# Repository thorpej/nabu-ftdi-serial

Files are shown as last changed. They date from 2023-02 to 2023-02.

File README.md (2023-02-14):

# nabu-ftdi-serial
A serial interposer board for NABU PCs with a FTDI USB-serial adapter and
hardware flow control

This is a simple serial interposer board for NABU PCs that intercepts
the Tx and Rx signals from the TR1863 UART and routes them to an FTDI
USB-serial adapter rather than to the RS422 line drivers on the NABU
main board.

In addition to intercepting the Tx and Rx signals, it also provides two
enhancements:

* The option to use a 1.8432MHz oscillator to generate a 115.2K baud
  rate on the UART, rather than the stock 111.8K baud that the NABU's
  clock generates.  Two different oscillator footprints are provided,
  for your convenience.  A jumper is provided to select the clock source.

* The option to enable hardware flow control.  This is done by connecting
  the TR1863's _DR_ signal (Data Received) to the _CTS_ input on the FTDI.
  Because _DR_ is active-high and _CTS_ is active-low, a pending receive
  interrupt effectively de-asserts _CTS_, which will cause the sender to
  pause transmitting until the interrupt has been serviced.

To build this board you're oging to need an FTDI USB -> serial interface
chip mounted on some sort of break-out board.  The board provides 2
footprints to provide some flexibility.

The first footprint is for a 6-pin right-angle pin header that is meant
for an Adafruit 6-pin female FTDI connector.  Such a connector can be
found on the [Adafruit FTDI Friend](https://www.adafruit.com/product/284),
the [Adafruit FTDI Serial TTL-232 Cable](https://www.adafruit.com/product/70),
or the [Adafruit FTDI Serial TTL-232 USB Type C 5V Cable](https://www.adafruit.com/product/4364).
There are other cables out there with a compatible 6-pin connector,
but I specifically referenced the pin configuration of the Adafruit
products.

The other option is one of the FTDI FT232RL boards that are all over
Ali Express.  I ordered [this one](https://www.aliexpress.us/item/2251832463833524.html),
but there are lots of identical boards floating around.

This board is 99.9% the work of Kris Sekula (MyGeekyHobby.com).  All I did
was add the hardware flow control modification.  Kudos to Kris for publishing
his idea [here](https://github.com/Kris-Sekula/NABU/tree/main/RS422Alternative).

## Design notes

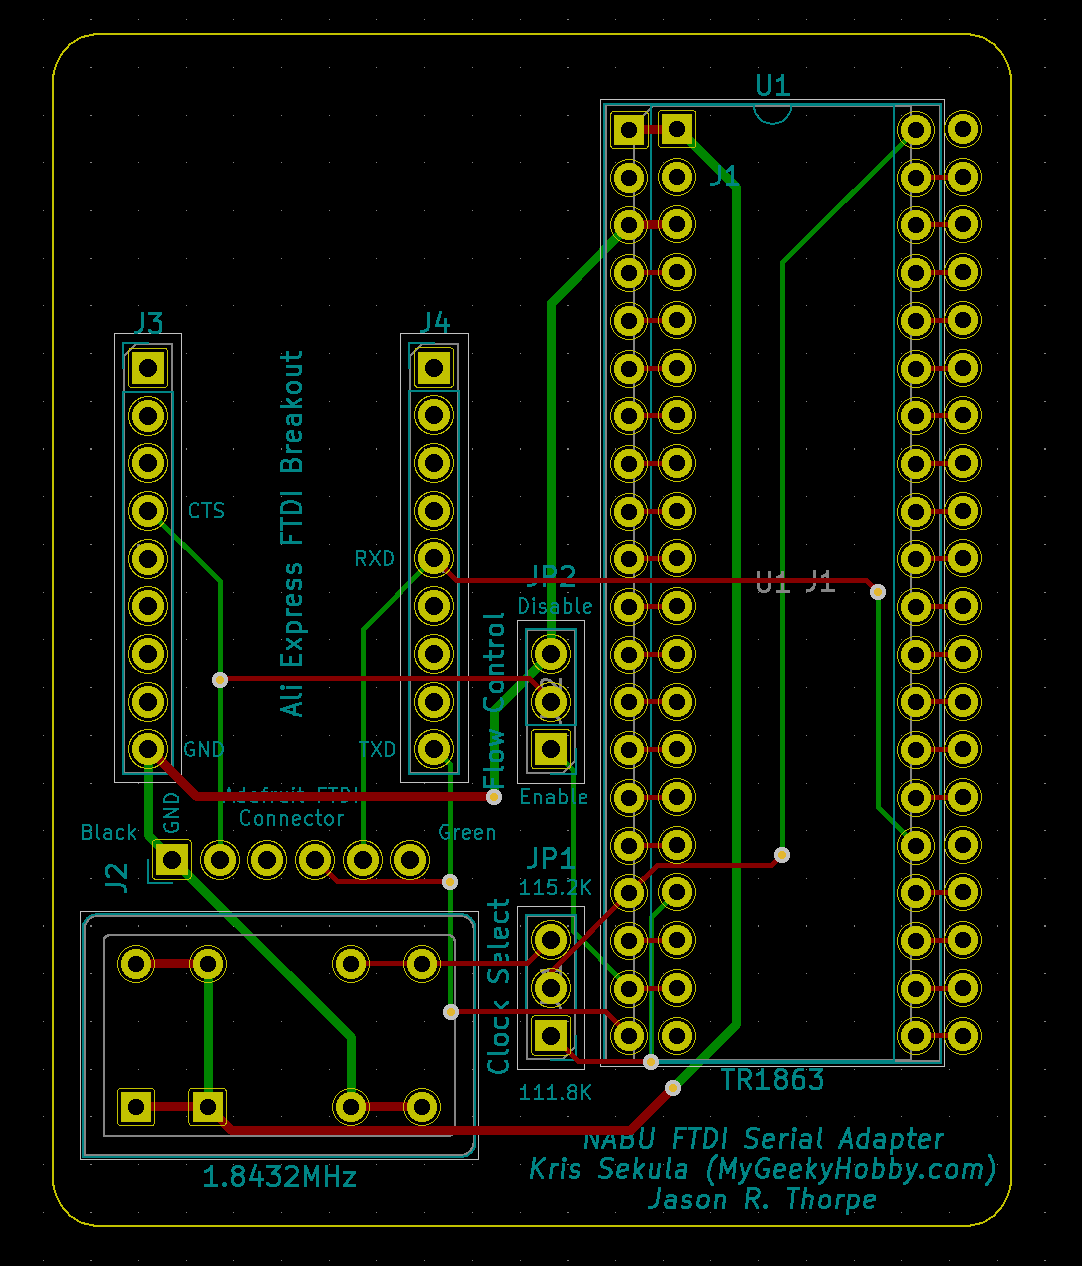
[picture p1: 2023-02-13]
nabu-ftdi-serial-pcb.png

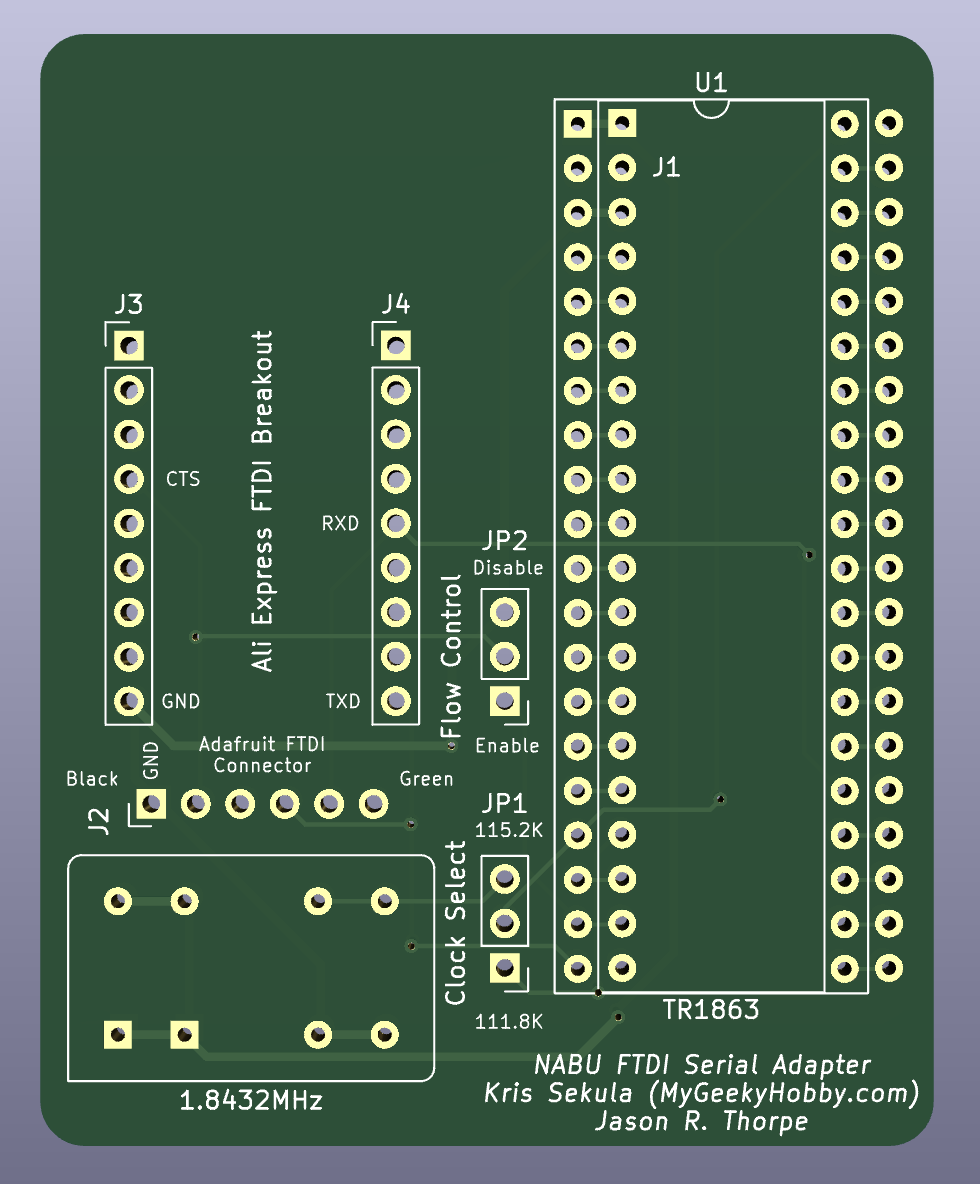
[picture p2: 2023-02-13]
nabu-ftdi-serial-pcb-render.png

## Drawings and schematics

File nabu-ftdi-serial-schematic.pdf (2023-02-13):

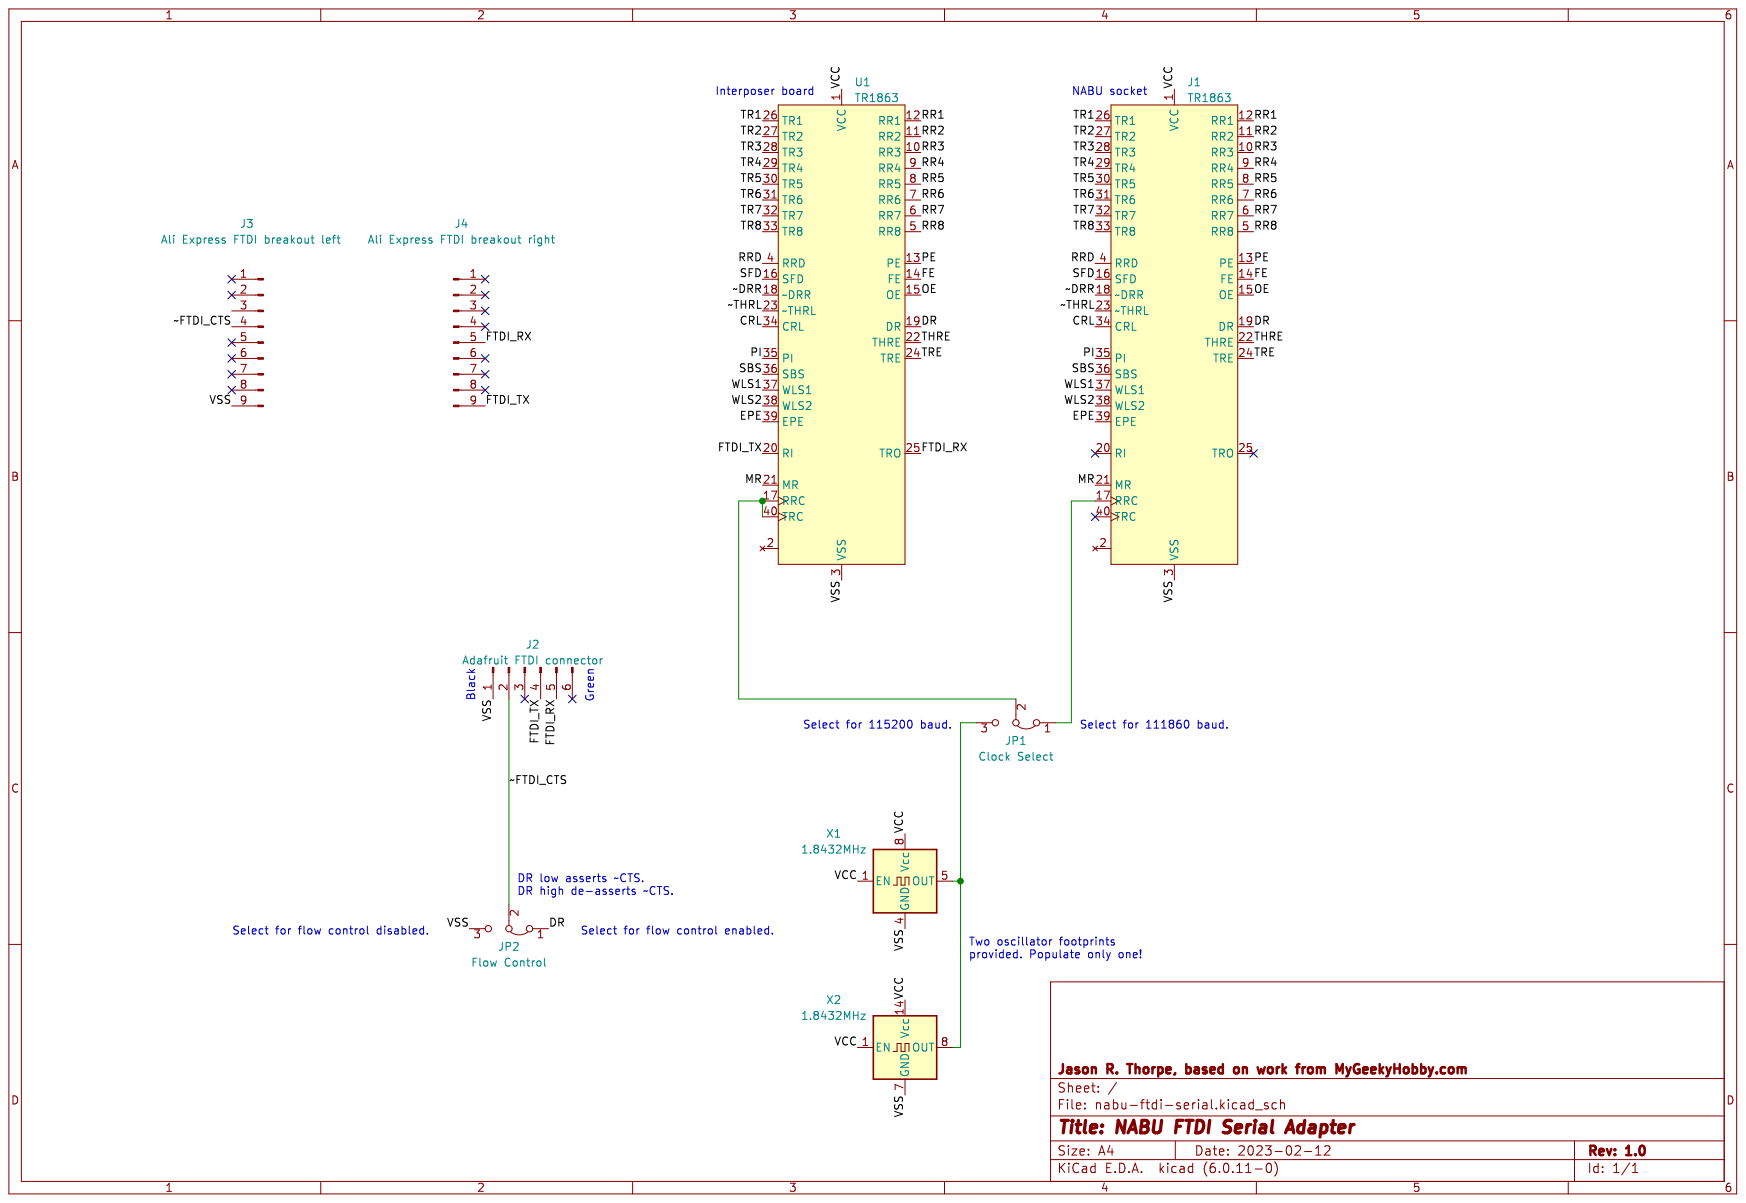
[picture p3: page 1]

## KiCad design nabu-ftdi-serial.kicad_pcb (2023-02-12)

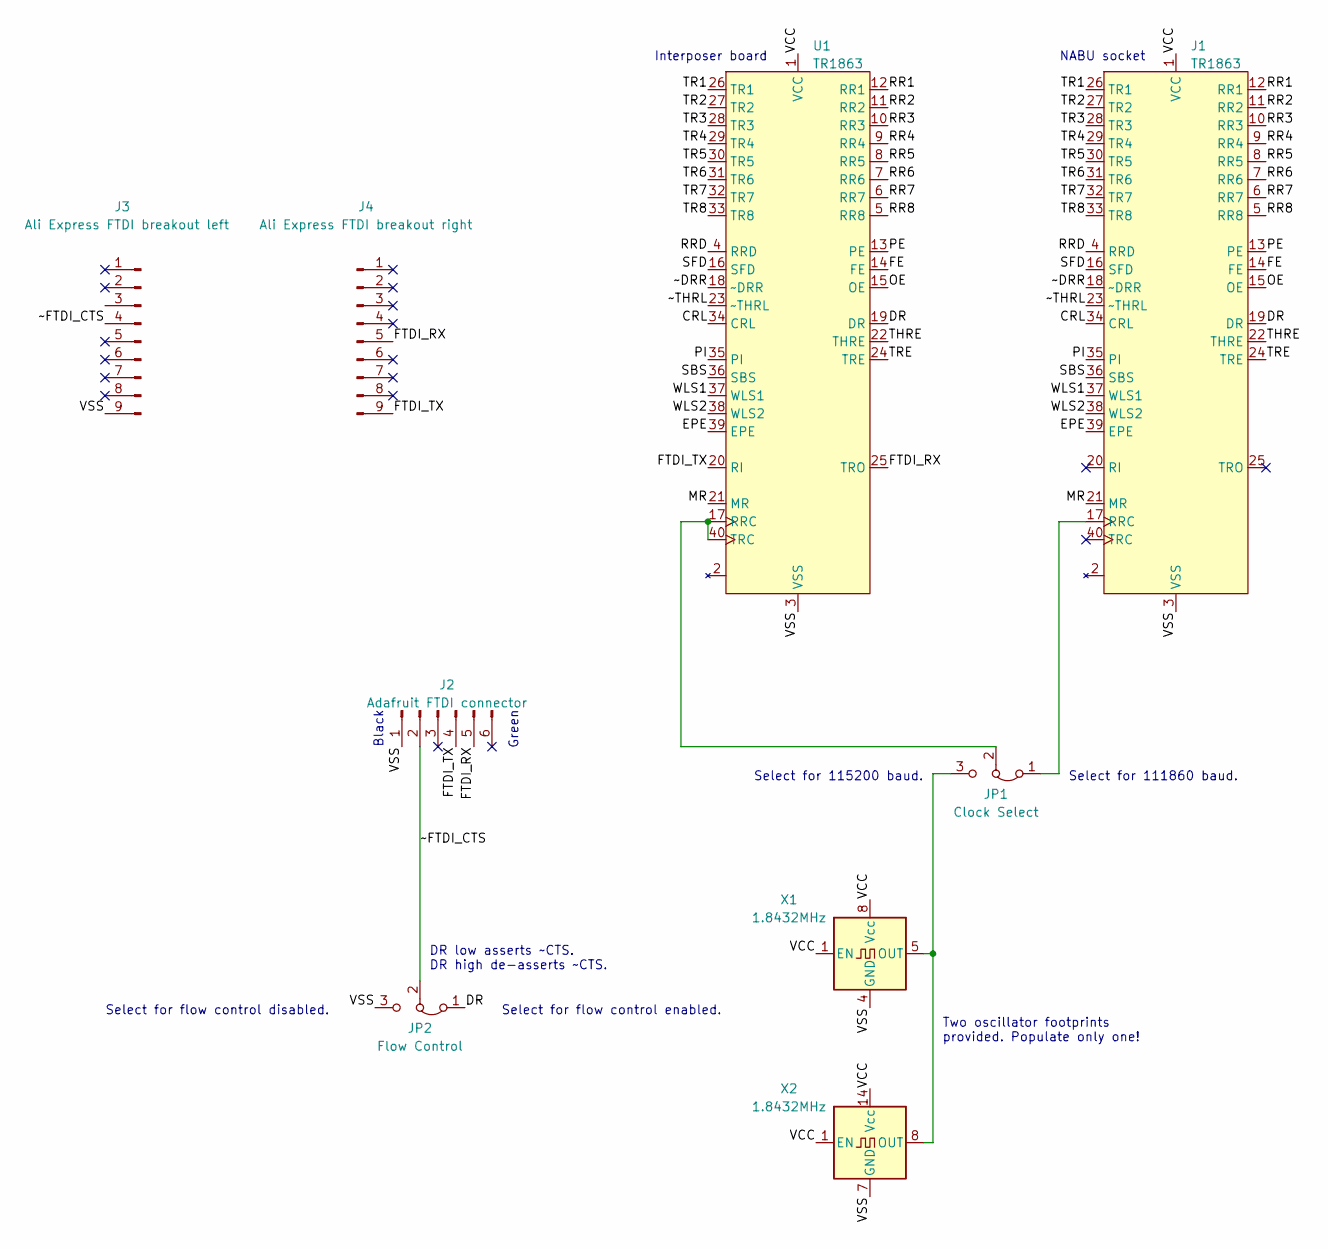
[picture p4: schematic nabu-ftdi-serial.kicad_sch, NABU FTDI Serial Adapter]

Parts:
J1: TR1863; DIP-40_W15.24mm
J2: Adafruit FTDI connector; PinHeader_1x06_P2.54mm_Horizontal
J3: Ali Express FTDI breakout left; PinHeader_1x09_P2.54mm_Vertical
J4: Ali Express FTDI breakout right; PinHeader_1x09_P2.54mm_Vertical
JP1: Clock Select; PinHeader_1x03_P2.54mm_Vertical
JP2: Flow Control; PinHeader_1x03_P2.54mm_Vertical
U1: TR1863; DIP-40_W15.24mm_Socket
X1: 1.8432MHz; Oscillator_DIP-8
X2: 1.8432MHz; Oscillator_DIP-14

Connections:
/CRL: J1.34 (CRL), U1.34 (CRL)
/DR: J1.19 (DR), JP2.1 (A), U1.19 (DR)
/EPE: J1.39 (EPE), U1.39 (EPE)
/FE: J1.14 (FE), U1.14 (FE)
/FTDI_RX: J2.5, J4.5, U1.25 (TRO)
/FTDI_TX: J2.4, J4.9, U1.20 (RI)
/MR: J1.21 (MR), U1.21 (MR)
/OE: J1.15 (OE), U1.15 (OE)
/PE: J1.13 (PE), U1.13 (PE)
/PI: J1.35 (PI), U1.35 (PI)
/RR1: J1.12 (RR1), U1.12 (RR1)
/RR2: J1.11 (RR2), U1.11 (RR2)
/RR3: J1.10 (RR3), U1.10 (RR3)
/RR4: J1.9 (RR4), U1.9 (RR4)
/RR5: J1.8 (RR5), U1.8 (RR5)
/RR6: J1.7 (RR6), U1.7 (RR6)
/RR7: J1.6 (RR7), U1.6 (RR7)
/RR8: J1.5 (RR8), U1.5 (RR8)
/RRD: J1.4 (RRD), U1.4 (RRD)
/SBS: J1.36 (SBS), U1.36 (SBS)
/SFD: J1.16 (SFD), U1.16 (SFD)
/THRE: J1.22 (THRE), U1.22 (THRE)
/TR1: J1.26 (TR1), U1.26 (TR1)
/TR2: J1.27 (TR2), U1.27 (TR2)
/TR3: J1.28 (TR3), U1.28 (TR3)
/TR4: J1.29 (TR4), U1.29 (TR4)
/TR5: J1.30 (TR5), U1.30 (TR5)
/TR6: J1.31 (TR6), U1.31 (TR6)
/TR7: J1.32 (TR7), U1.32 (TR7)
/TR8: J1.33 (TR8), U1.33 (TR8)
/TRE: J1.24 (TRE), U1.24 (TRE)
/VCC: J1.1 (VCC), U1.1 (VCC), X1.1 (EN), X1.8 (Vcc), X2.1 (EN), X2.14 (Vcc)
/VSS: J1.3 (VSS), J2.1, J3.9, JP2.3 (B), U1.3 (VSS), X1.4 (GND), X2.7 (GND)
/WLS1: J1.37 (WLS1), U1.37 (WLS1)
/WLS2: J1.38 (WLS2), U1.38 (WLS2)
/~DRR: J1.18 (~DRR), U1.18 (~DRR)
/~FTDI_CTS: J2.2, J3.4, JP2.2 (C)
/~THRL: J1.23 (~THRL), U1.23 (~THRL)
unnamed: J1.17 (RRC), JP1.1 (A)
unnamed: JP1.3 (B), X1.5 (OUT), X2.8 (OUT)
unnamed: JP1.2 (C), U1.17 (RRC), U1.40 (TRC)

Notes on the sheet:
Green
Select for flow control disabled.
Select for flow control enabled.
NABU socket
Interposer board
Two oscillator footprints provided. Populate only one!
Select for 111860 baud.
Black
DR low asserts ~CTS. DR high de-asserts ~CTS.
Select for 115200 baud.

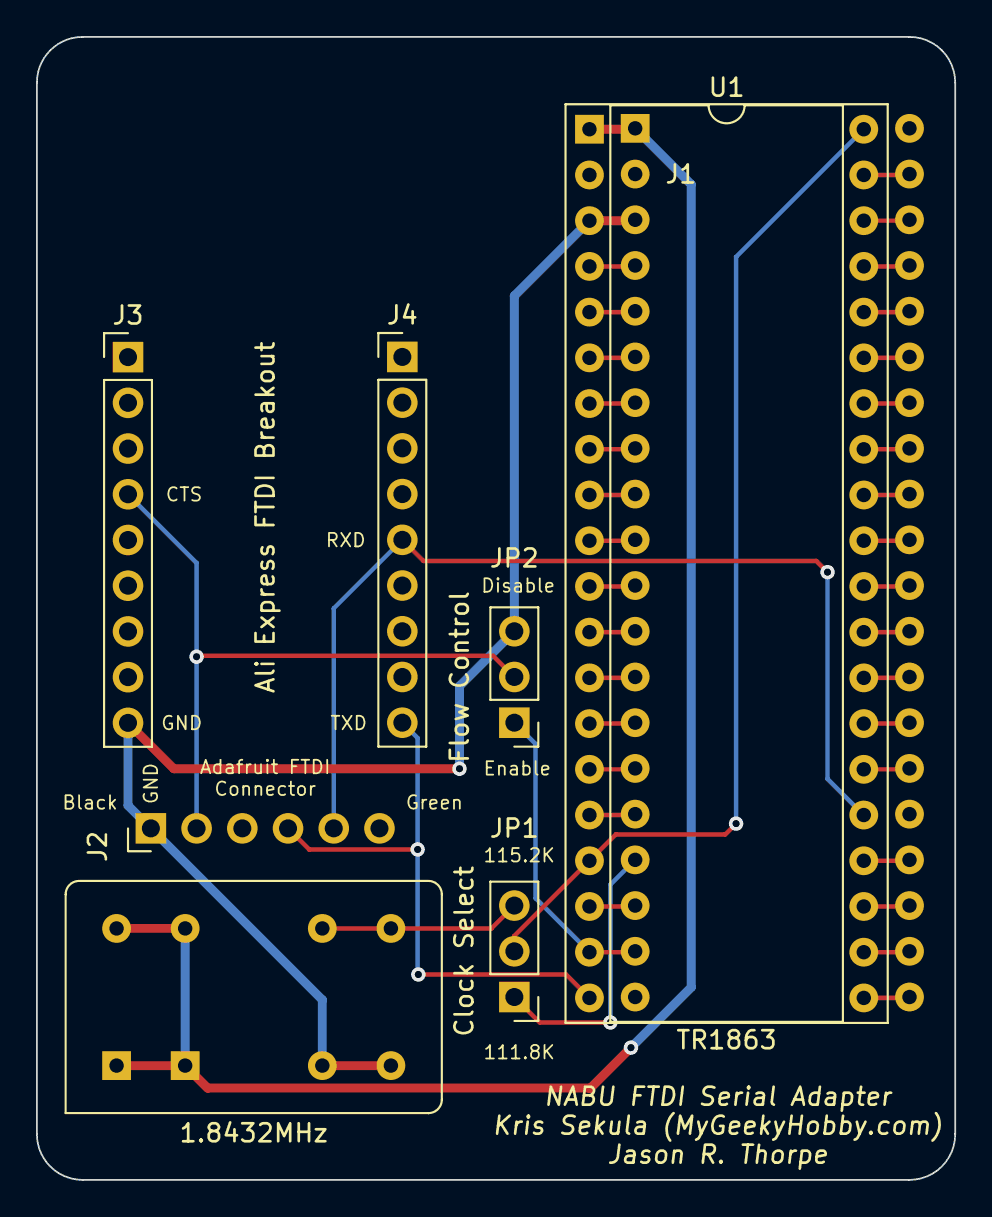
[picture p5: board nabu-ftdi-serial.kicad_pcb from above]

Board: 2 copper layers, 51.0 x 63.5 mm, 9 parts (0 on the bottom side), 41 nets.

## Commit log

2023-02-12 Add design files for the FDTI serial interposer board.
    [nabu-ftdi-serial.kicad_pcb, nabu-ftdi-serial.kicad_sch]
2023-02-13 Add Gerbers for 1.0.
    [nabu-ftdi-serial-B_Cu.gbr, nabu-ftdi-serial-B_Mask.gbr, nabu-ftdi-serial-B_Silkscreen.gbr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]
2023-02-13 Add easily-viewable images of the schematic and PCB.
2023-02-14 Add a reference to the serial board options.
